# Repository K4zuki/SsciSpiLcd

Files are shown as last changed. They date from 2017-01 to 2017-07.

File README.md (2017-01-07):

# idea

- breadboard-able breakout board for color SPI memory LCD from Switch Science
    - https://www.switch-science.com/catalog/2858/

# spec

26.02x27.82 mm<sup>2</sup> LCD
- 42x35mm pcb
    - 4~6 panelize
- AkiSpiLcd compatible and extention
    - 541 buffer + 3-state buffer + NAND
- 23K256 SRAM
    - persudo DMA
- 3.3V LDO
- 1x8 pin headers left and right
    - VDD = 5V
    - GND
    - SPI.SCK
    - SPI.MOSI
    - SPI.MISO
    - SPI.CSL
    - SPI.CSR
    - LCD.DISP

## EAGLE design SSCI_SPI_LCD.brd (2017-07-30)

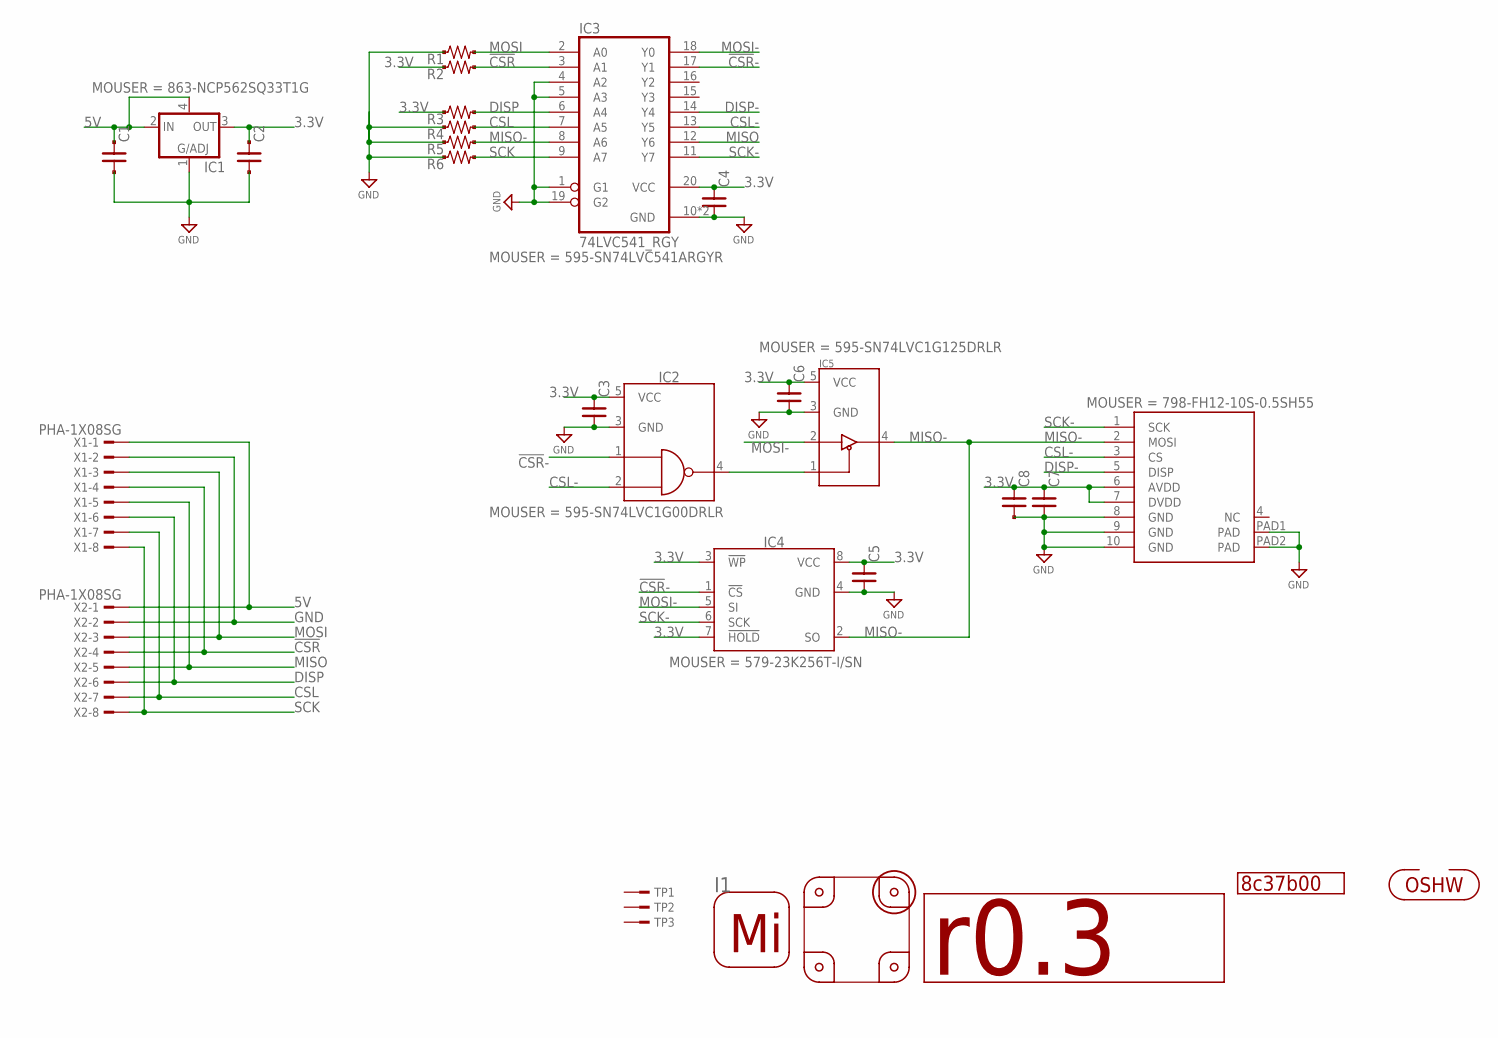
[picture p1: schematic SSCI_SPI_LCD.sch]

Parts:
C1, C2: C_SMD_10U_1608; CR_1608
C3, C4, C5, C6, C7, C8: C_SMD_0.1U_1005; C0402
GIT1: 8c37b00; GIT-REVISION_1.2
I1: ICON_MINLAB_5.2S; ICON_MINLAB_5.2MM
IC1: LDO4_3.3_SC82-AB; SOT130P220X135-4N
IC2: 74LVC1G00_DRL; SOT50P160X120-5N
IC3: 74LVC541_RGY; QFN50P460X360-20N
IC4: IC_MEMORY_8P_23K256-I_SOP; IC_08_1.27_150MIL
IC5: 74LVC1G125_DRL; SOT50P160X120-5N
ICON1: r0.3; ICON_REVISION1.7
ICON2: ICON_OSHW
LCD1: LCD_GLCD_400X240
P1, P2, P3, P4: PCB_CORNER_NH
R1, R2, R3, R4, R5, R6: R_US_10K_1005; C0402
TP1, TP2, TP3: TESTPAD_F; FIDUCIAL
X1, X2: PHA-1X08SG

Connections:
3.3V: C2.1, C3.1, C4.1, C5.1, C6.1, C7.1, C8.1, IC1.3 (OUT), IC2.5 (VCC), IC3.20 (VCC), IC4.3 (!WP), IC4.7 (!HOLD), IC4.8 (VCC), IC5.5 (VCC), LCD1.6 (AVDD), LCD1.7 (DVDD), R2.1, R3.1
5V: C1.1, IC1.2 (IN), IC1.4 (OUT/EN/NC), X1.1, X2.1
!CSR!: IC3.3 (A1), R2.2, X1.4, X2.4
!CSR!-: IC2.1 (1A), IC3.17 (Y1), IC4.1 (!CS)
CSL: IC3.7 (A5), R4.2, X1.7, X2.7
CSL-: IC2.2 (1B), IC3.13 (Y5), LCD1.3 (CS)
DISP: IC3.6 (A4), R3.2, X1.6, X2.6
DISP-: IC3.14 (Y4), LCD1.5 (DISP)
GND: C1.2, C2.2, C3.2, C4.2, C5.2, C6.2, C7.2, C8.2, IC1.1 (ADJ), IC2.3 (GND), IC3.1 (G1), IC3.4 (A2), IC3.5 (A3), IC3.10 (GND), IC3.19 (G2), IC3.EP (GND), IC4.4 (GND), IC5.3 (GND), LCD1.8 (GND), LCD1.9 (GND), LCD1.10 (GND), LCD1.PAD1 (PAD), LCD1.PAD2 (PAD), R1.1, R4.1, R5.1, R6.1, X1.2, X2.2
MISO: IC3.12 (Y6), X1.5, X2.5
MISO-: IC3.8 (A6), IC4.2 (SO), IC5.4 (Y), LCD1.2 (MOSI), R5.2
MOSI: IC3.2 (A0), R1.2, X1.3, X2.3
MOSI-: IC3.18 (Y0), IC4.5 (SI), IC5.2 (A)
unnamed: IC2.4 (1Y), IC5.1 (!OE!)
SCK: IC3.9 (A7), R6.2, X1.8, X2.8
SCK-: IC3.11 (Y7), IC4.6 (SCK), LCD1.1 (SCK)

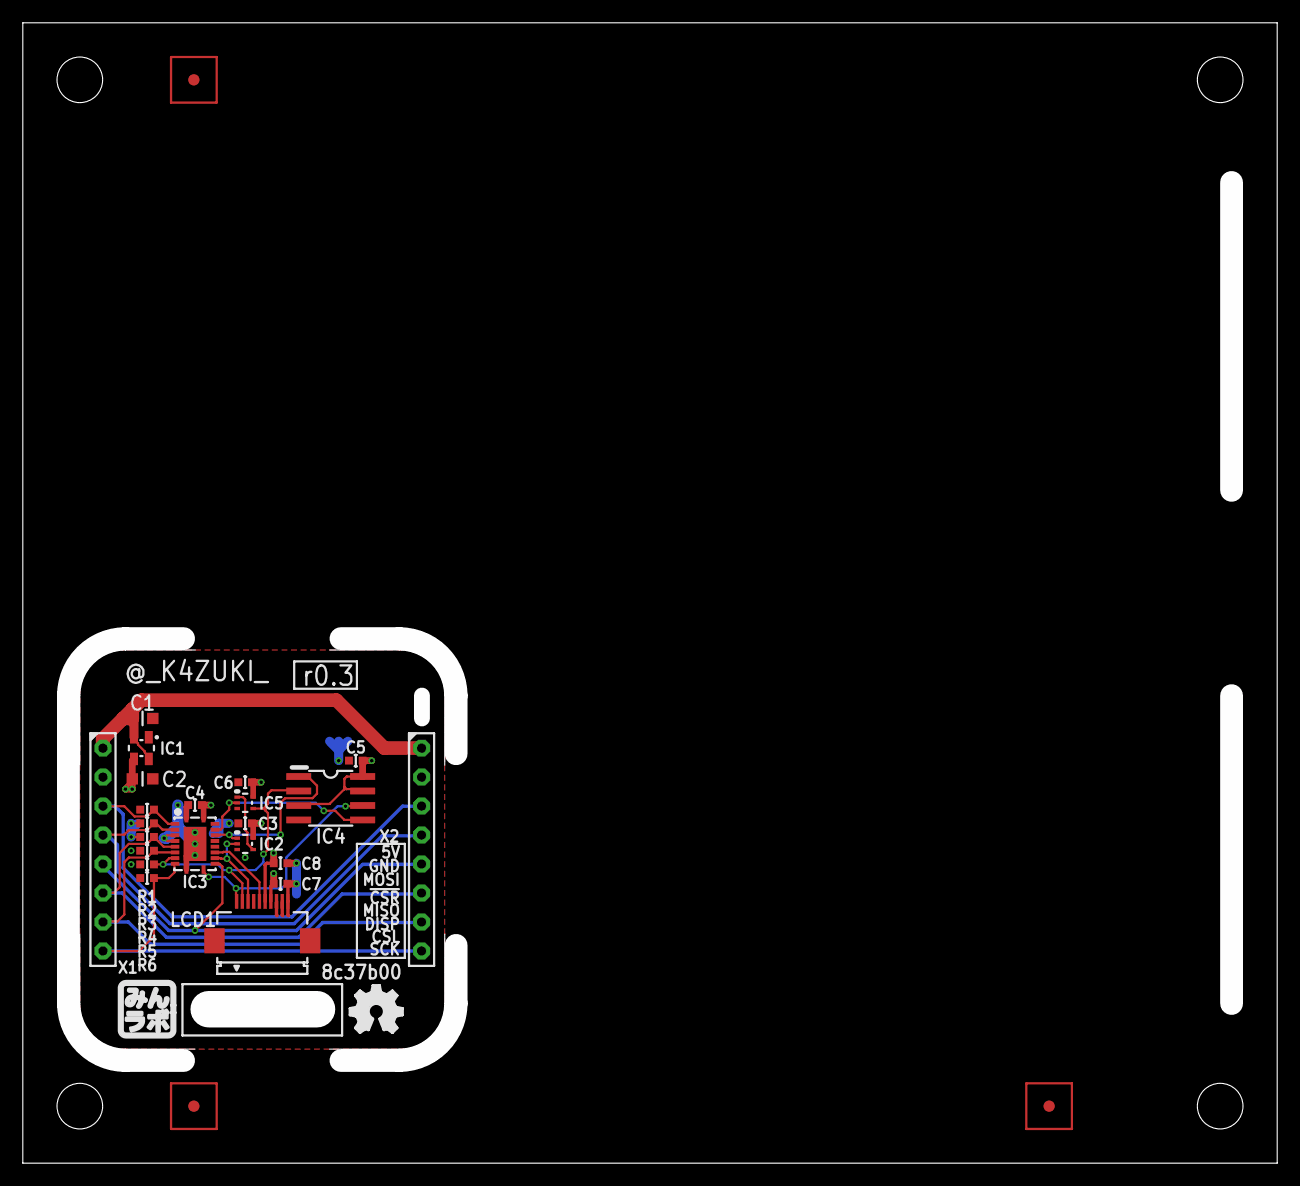
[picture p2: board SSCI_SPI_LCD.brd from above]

Board: 2 copper layers, 110.0 x 100.0 mm, 33 parts (0 on the bottom side), 16 nets.

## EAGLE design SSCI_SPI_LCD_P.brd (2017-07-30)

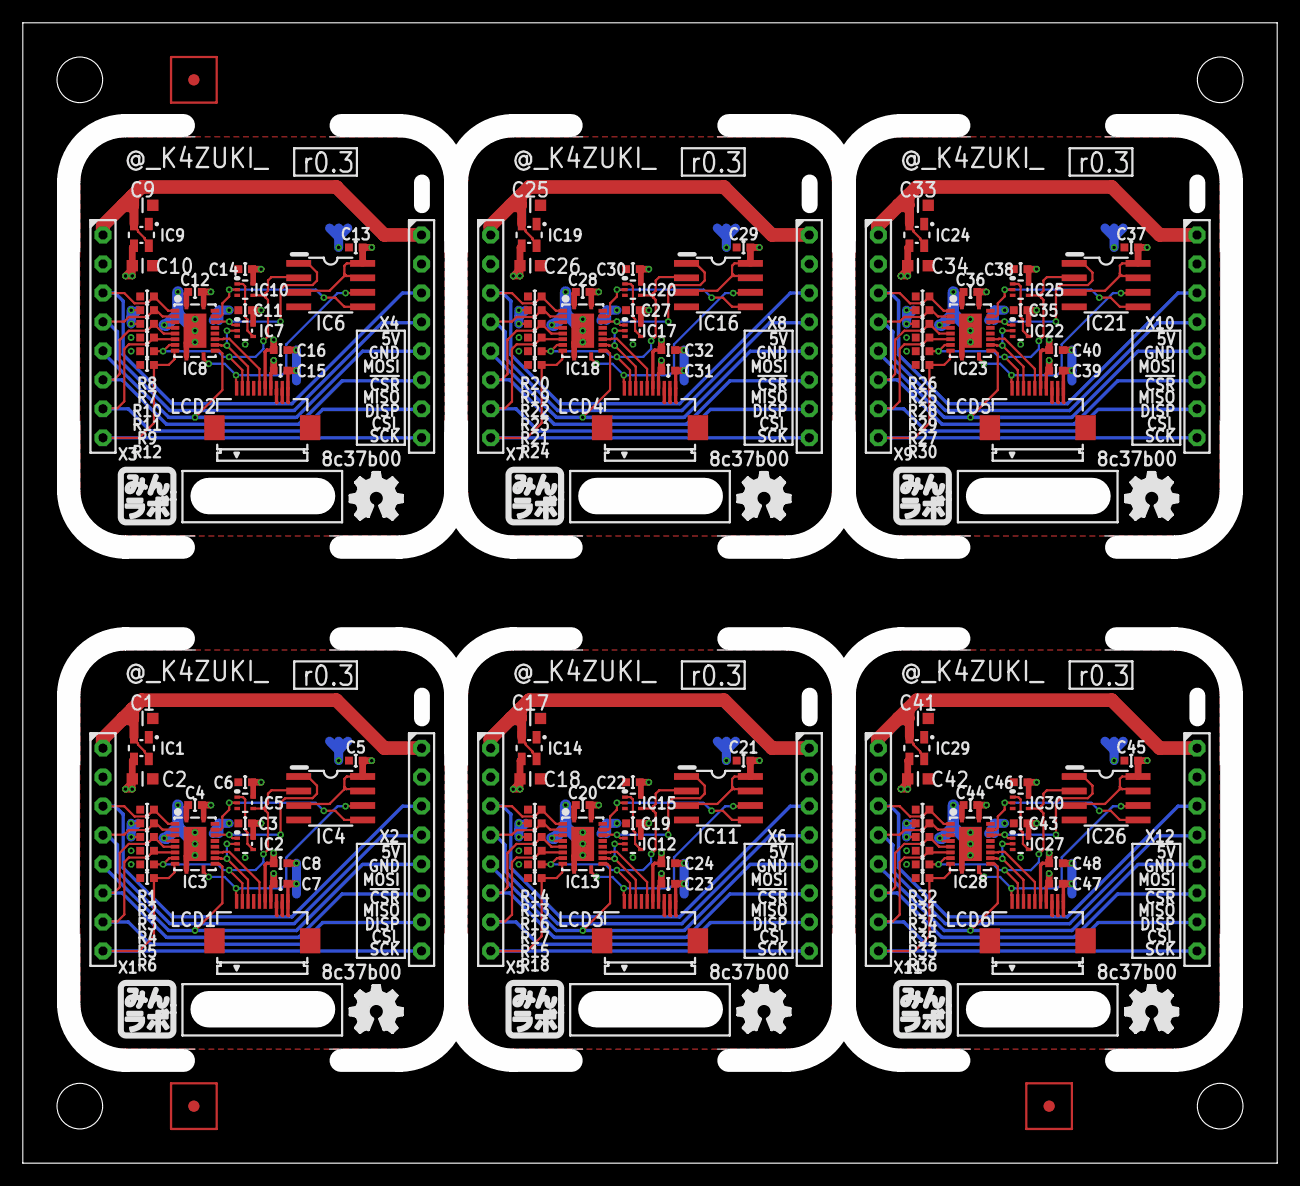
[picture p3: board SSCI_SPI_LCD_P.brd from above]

Board: 2 copper layers, 110.0 x 100.0 mm, 183 parts (0 on the bottom side), 96 nets.

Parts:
C1, C2, C9, C10, C17, C18, C25, C26, C33, C34, C41, C42: CR_1608
C3, C4, C5, C6, C7, C8, C11, C12, C13, C14, C15, C16, C19, C20, C21, C22, C23, C24, C27, C28, C29, C30, C31, C32, C35, C36, C37, C38, C39, C40, C43, C44, C45, C46, C47, C48: C0402
GIT1, GIT2, GIT3, GIT4, GIT5, GIT6: 8c37b00; GIT-REVISION_1.2
I1, I2, I3, I4, I5, I6: ICON_MINLAB_5.2MM
IC1, IC9, IC14, IC19, IC24, IC29: SOT130P220X135-4N
IC2, IC5, IC7, IC10, IC12, IC15, IC17, IC20, IC22, IC25, IC27, IC30: SOT50P160X120-5N
IC3, IC8, IC13, IC18, IC23, IC28: 74LVC541_RGY; QFN50P460X360-20N
IC4, IC6, IC11, IC16, IC21, IC26: IC_08_1.27_150MIL
ICON1, ICON3, ICON5, ICON7, ICON9, ICON11: r0.3; ICON_REVISION1.7
ICON2, ICON4, ICON6, ICON8, ICON10, ICON12: ICON_OSHW
LCD1, LCD2, LCD3, LCD4, LCD5, LCD6: LCD_GLCD_400X240
P1, P2, P3, P4, P5, P6, P7, P8, P9, P10, P11, P12, P13, P14, P15, P16, P17, P18, P19, P20, P21, P22, P23, P24: PCB_CORNER_NH
R1, R2, R3, R4, R5, R6, R7, R8, R9, R10, R11, R12, R13, R14, R15, R16, R17, R18, R19, R20, R21, R22, R23, R24, R25, R26, R27, R28, R29, R30, R31, R32, R33, R34, R35, R36: C0402
TP1, TP2, TP3: FIDUCIAL
X1, X2, X3, X4, X5, X6, X7, X8, X9, X10, X11, X12: PHA-1X08SG

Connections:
3.3V: C2.1, C3.1, C4.1, C5.1, C6.1, C7.1, C8.1, IC1.3, IC2.5, IC3.20, IC4.3, IC4.7, IC4.8, IC5.5, LCD1.6, LCD1.7, R2.1, R3.1
3.3V1: C10.1, C11.1, C12.1, C13.1, C14.1, C15.1, C16.1, IC6.3, IC6.7, IC6.8, IC7.5, IC8.20, IC9.3, IC10.5, LCD2.6, LCD2.7, R7.1, R10.1
3.3V2: C18.1, C19.1, C20.1, C21.1, C22.1, C23.1, C24.1, IC11.3, IC11.7, IC11.8, IC12.5, IC13.20, IC14.3, IC15.5, LCD3.6, LCD3.7, R13.1, R16.1
3.3V3: C26.1, C27.1, C28.1, C29.1, C30.1, C31.1, C32.1, IC16.3, IC16.7, IC16.8, IC17.5, IC18.20, IC19.3, IC20.5, LCD4.6, LCD4.7, R19.1, R22.1
3.3V4: C34.1, C35.1, C36.1, C37.1, C38.1, C39.1, C40.1, IC21.3, IC21.7, IC21.8, IC22.5, IC23.20, IC24.3, IC25.5, LCD5.6, LCD5.7, R25.1, R28.1
3.3V5: C42.1, C43.1, C44.1, C45.1, C46.1, C47.1, C48.1, IC26.3, IC26.7, IC26.8, IC27.5, IC28.20, IC29.3, IC30.5, LCD6.6, LCD6.7, R31.1, R34.1
5V: C1.1, IC1.2, IC1.4, X1.1, X2.1
5V1: C9.1, IC9.2, IC9.4, X3.1, X4.1
5V2: C17.1, IC14.2, IC14.4, X5.1, X6.1
5V3: C25.1, IC19.2, IC19.4, X7.1, X8.1
5V4: C33.1, IC24.2, IC24.4, X9.1, X10.1
5V5: C41.1, IC29.2, IC29.4, X11.1, X12.1
!CSR!: IC3.3, R2.2, X1.4, X2.4
!CSR!1: IC8.3, R7.2, X3.4, X4.4
!CSR!2: IC13.3, R13.2, X5.4, X6.4
!CSR!3: IC18.3, R19.2, X7.4, X8.4
!CSR!4: IC23.3, R25.2, X9.4, X10.4
!CSR!5: IC28.3, R31.2, X11.4, X12.4
!CSR!-: IC2.1, IC3.17, IC4.1
!CSR!-1: IC6.1, IC7.1, IC8.17
!CSR!-2: IC11.1, IC12.1, IC13.17
!CSR!-3: IC16.1, IC17.1, IC18.17
!CSR!-4: IC21.1, IC22.1, IC23.17
!CSR!-5: IC26.1, IC27.1, IC28.17
CSL: IC3.7, R4.2, X1.7, X2.7
CSL1: IC8.7, R11.2, X3.7, X4.7
CSL2: IC13.7, R17.2, X5.7, X6.7
CSL3: IC18.7, R23.2, X7.7, X8.7
CSL4: IC23.7, R29.2, X9.7, X10.7
CSL5: IC28.7, R35.2, X11.7, X12.7
CSL-: IC2.2, IC3.13, LCD1.3
CSL-1: IC7.2, IC8.13, LCD2.3
CSL-2: IC12.2, IC13.13, LCD3.3
CSL-3: IC17.2, IC18.13, LCD4.3
CSL-4: IC22.2, IC23.13, LCD5.3
CSL-5: IC27.2, IC28.13, LCD6.3
DISP: IC3.6, R3.2, X1.6, X2.6
DISP1: IC8.6, R10.2, X3.6, X4.6
DISP2: IC13.6, R16.2, X5.6, X6.6
DISP3: IC18.6, R22.2, X7.6, X8.6
DISP4: IC23.6, R28.2, X9.6, X10.6
DISP5: IC28.6, R34.2, X11.6, X12.6
DISP-: IC3.14, LCD1.5
DISP-1: IC8.14, LCD2.5
DISP-2: IC13.14, LCD3.5
DISP-3: IC18.14, LCD4.5
DISP-4: IC23.14, LCD5.5
DISP-5: IC28.14, LCD6.5
GND: C1.2, C2.2, C3.2, C4.2, C5.2, C6.2, C7.2, C8.2, IC1.1, IC2.3, IC3.1, IC3.4, IC3.5, IC3.10, IC3.19, IC3.EP, IC4.4, IC5.3, LCD1.8, LCD1.9, LCD1.10, LCD1.PAD1, LCD1.PAD2, R1.1, R4.1, R5.1, R6.1, X1.2, X2.2
GND1: C9.2, C10.2, C11.2, C12.2, C13.2, C14.2, C15.2, C16.2, IC6.4, IC7.3, IC8.1, IC8.4, IC8.5, IC8.10, IC8.19, IC8.EP, IC9.1, IC10.3, LCD2.8, LCD2.9, LCD2.10, LCD2.PAD1, LCD2.PAD2, R8.1, R9.1, R11.1, R12.1, X3.2, X4.2
GND2: C17.2, C18.2, C19.2, C20.2, C21.2, C22.2, C23.2, C24.2, IC11.4, IC12.3, IC13.1, IC13.4, IC13.5, IC13.10, IC13.19, IC13.EP, IC14.1, IC15.3, LCD3.8, LCD3.9, LCD3.10, LCD3.PAD1, LCD3.PAD2, R14.1, R15.1, R17.1, R18.1, X5.2, X6.2
GND3: C25.2, C26.2, C27.2, C28.2, C29.2, C30.2, C31.2, C32.2, IC16.4, IC17.3, IC18.1, IC18.4, IC18.5, IC18.10, IC18.19, IC18.EP, IC19.1, IC20.3, LCD4.8, LCD4.9, LCD4.10, LCD4.PAD1, LCD4.PAD2, R20.1, R21.1, R23.1, R24.1, X7.2, X8.2
GND4: C33.2, C34.2, C35.2, C36.2, C37.2, C38.2, C39.2, C40.2, IC21.4, IC22.3, IC23.1, IC23.4, IC23.5, IC23.10, IC23.19, IC23.EP, IC24.1, IC25.3, LCD5.8, LCD5.9, LCD5.10, LCD5.PAD1, LCD5.PAD2, R26.1, R27.1, R29.1, R30.1, X9.2, X10.2
GND5: C41.2, C42.2, C43.2, C44.2, C45.2, C46.2, C47.2, C48.2, IC26.4, IC27.3, IC28.1, IC28.4, IC28.5, IC28.10, IC28.19, IC28.EP, IC29.1, IC30.3, LCD6.8, LCD6.9, LCD6.10, LCD6.PAD1, LCD6.PAD2, R32.1, R33.1, R35.1, R36.1, X11.2, X12.2
MISO: IC3.12, X1.5, X2.5
MISO1: IC8.12, X3.5, X4.5
MISO2: IC13.12, X5.5, X6.5
MISO3: IC18.12, X7.5, X8.5
MISO4: IC23.12, X9.5, X10.5
MISO5: IC28.12, X11.5, X12.5
MISO-: IC3.8, IC4.2, IC5.4, LCD1.2, R5.2
MISO-1: IC6.2, IC8.8, IC10.4, LCD2.2, R9.2
MISO-2: IC11.2, IC13.8, IC15.4, LCD3.2, R15.2
MISO-3: IC16.2, IC18.8, IC20.4, LCD4.2, R21.2
MISO-4: IC21.2, IC23.8, IC25.4, LCD5.2, R27.2
MISO-5: IC26.2, IC28.8, IC30.4, LCD6.2, R33.2
MOSI: IC3.2, R1.2, X1.3, X2.3
MOSI1: IC8.2, R8.2, X3.3, X4.3
MOSI2: IC13.2, R14.2, X5.3, X6.3
MOSI3: IC18.2, R20.2, X7.3, X8.3
MOSI4: IC23.2, R26.2, X9.3, X10.3
MOSI5: IC28.2, R32.2, X11.3, X12.3
MOSI-: IC3.18, IC4.5, IC5.2
MOSI-1: IC6.5, IC8.18, IC10.2
MOSI-2: IC11.5, IC13.18, IC15.2
MOSI-3: IC16.5, IC18.18, IC20.2
MOSI-4: IC21.5, IC23.18, IC25.2
MOSI-5: IC26.5, IC28.18, IC30.2
unnamed: IC7.4, IC10.1
unnamed: IC2.4, IC5.1
unnamed: IC12.4, IC15.1
unnamed: IC17.4, IC20.1
unnamed: IC22.4, IC25.1
unnamed: IC27.4, IC30.1
SCK: IC3.9, R6.2, X1.8, X2.8
SCK1: IC8.9, R12.2, X3.8, X4.8
SCK2: IC13.9, R18.2, X5.8, X6.8
SCK3: IC18.9, R24.2, X7.8, X8.8
SCK4: IC23.9, R30.2, X9.8, X10.8
SCK5: IC28.9, R36.2, X11.8, X12.8
SCK-: IC3.11, IC4.6, LCD1.1
SCK-1: IC6.6, IC8.11, LCD2.1
SCK-2: IC11.6, IC13.11, LCD3.1
SCK-3: IC16.6, IC18.11, LCD4.1
SCK-4: IC21.6, IC23.11, LCD5.1
SCK-5: IC26.6, IC28.11, LCD6.1

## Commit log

2016-10-11 add sch/brd files
    [SSCI_SPI_LCD.brd, SSCI_SPI_LCD.sch]
2016-10-11 r0.1 prototype
    [SSCI_SPI_LCD.brd, SSCI_SPI_LCD.sch]
2016-10-11 connectors silk
    [SSCI_SPI_LCD.brd, SSCI_SPI_LCD.sch]
2016-10-12 revision 0.1
    [SSCI_SPI_LCD.brd, SSCI_SPI_LCD.sch]
2016-10-12 not Dimension but tRestrict/bRestrict to cut copper pour
    [SSCI_SPI_LCD.brd, SSCI_SPI_LCD.sch]
2016-10-19 better routing; library update
    [SSCI_SPI_LCD.brd, SSCI_SPI_LCD.sch]
2016-10-22 Board size get narrower by 2mm; related moves; library updates
    Board size:
    42x35mm -> 40x35mm
    Moves:
    - X1/2 connectors
    - CR and ICs
    - Version/Revision/Names silk
    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
    [SSCI_SPI_LCD.brd, SSCI_SPI_LCD.sch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]
2016-10-24 apply changes to panelising file
    [SSCI_SPI_LCD.brd, SSCI_SPI_LCD.sch, SSCI_SPI_LCD_P.brd]
2016-11-14 add MinLab icon; moves
    [SSCI_SPI_LCD.brd, SSCI_SPI_LCD.sch]
2016-11-14 update libraries; update panelise; update gerbers
    [SSCI_SPI_LCD.brd, SSCI_SPI_LCD.sch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]
2017-01-03 [ BRD ] add fiducial
    [SSCI_SPI_LCD.brd, SSCI_SPI_LCD.sch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]
2017-01-03 [ BRD ] replace pinheader; revision 0.3; add corner 4.0mm holes
    [SSCI_SPI_LCD.brd, SSCI_SPI_LCD.sch]
2017-01-03 [ BRD ] add C5 ground via; git revision update
    [SSCI_SPI_LCD.brd, SSCI_SPI_LCD.sch]
2017-01-03 [ BRD ] add measures
    - hole to hole
    - board edge to pin header center
    [SSCI_SPI_LCD.brd, SSCI_SPI_LCD.sch]
2017-01-03 [ BRD ] add pin silk on bottom
    [SSCI_SPI_LCD.brd]
2017-01-03 [ BRD ] X1/X2 silk moved
    [SSCI_SPI_LCD.brd]
2017-01-03 [ BRD ] panelized
    [SSCI_SPI_LCD_P.brd]
2017-01-03 gerber out with bottom silk
    [SSCI_SPI_LCD_P.GBL, SSCI_SPI_LCD_P.GBO, SSCI_SPI_LCD_P.GBS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]
2017-01-07 update git revision; remove unnecessary tRestrict
    [SSCI_SPI_LCD.brd, SSCI_SPI_LCD.sch]
2017-01-27 pin header distance get 200mil narrower
    - 1300mil -> 1100mil
    - matches with "standard" breadboard
    [SSCI_SPI_LCD.brd, SSCI_SPI_LCD.sch]
2017-07-26 update library
    [SSCI_SPI_LCD.brd, SSCI_SPI_LCD.sch]
2017-07-26 outline resized
    - no more corner screw holes
    - still panelized in 110x100(3x2)
    [SSCI_SPI_LCD.brd, SSCI_SPI_LCD.sch]
2017-07-26 R3 connected to 3.3V (to pull up DISP pin)
    - left-top corner(at LCD top view) has key-hole
    [SSCI_SPI_LCD.brd, SSCI_SPI_LCD.sch]
2017-07-30 keyhole replaced by milling
    X2 note is tPlace layer
    [SSCI_SPI_LCD.brd, SSCI_SPI_LCD.sch]
2017-07-30 8c37b00 panelized
    [SSCI_SPI_LCD.brd, SSCI_SPI_LCD.sch, SSCI_SPI_LCD_P.brd]
2017-07-30 r0.3 gerber updated
    [SSCI_SPI_LCD_P.GBL, SSCI_SPI_LCD_P.GBO, SSCI_SPI_LCD_P.GBS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]
